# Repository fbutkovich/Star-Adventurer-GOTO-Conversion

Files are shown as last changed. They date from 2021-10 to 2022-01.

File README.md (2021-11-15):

# Star-Adventurer-GOTO-Conversion
Source code, schematics and 3D printing files for the conversion of the SkyWatcher Star Adventurer to a full GOTO equatorial telescope mount. The conversion will require soldering skills in order to splice the yellow and blue wires from the 
brushed DC motor inside the stock SA. The current version of the Python GUI was developed with Python 3.9. The included "Adafruit_Motor_Shield_V2_Library" MUST be used vs. the default version available to the public, as it was modified to 
support accurate stepper motor stepping. The helper library "ParseMotorParameters" must also be placed inside the C:\Users\username\Documents\Arduino\libraries folder if modifying/re-uploading the source code. 

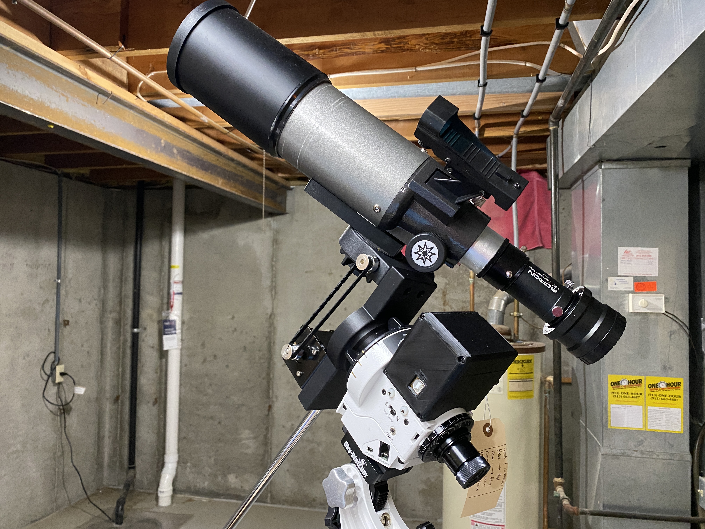
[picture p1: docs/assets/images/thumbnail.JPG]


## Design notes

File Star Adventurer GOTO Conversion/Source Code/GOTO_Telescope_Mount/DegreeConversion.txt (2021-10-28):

The following is a conversion method for how long the RA motor inside the Star Adventuerer should run in seconds to 
move the RA axis a given amount of degrees.

Motor shaft -> 1st spur gear is 327:1 possibly 350:1?

18RPM on 1st spur gear * 327 = 5886RPM

5886RPM/70000=0.084RPM

1/0.084RPM=12m

360deg/12m=30deg/m=0.5deg/s

to move 5deg it would take 5/0.5=10s/60s=0m10s

total reduction ratio between motor shaft and dovetail bracket is 70000:1

With the speed set to 150(5886RPM), the voltage is 7.5V across the motor which is optimal.

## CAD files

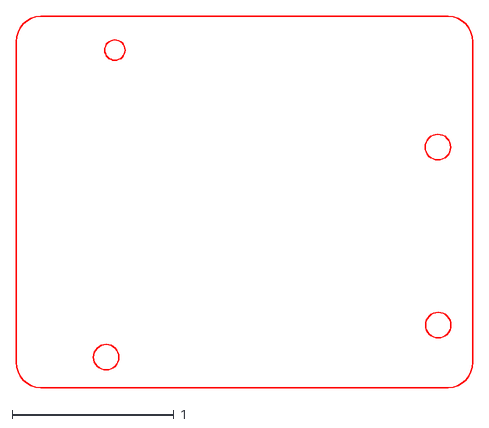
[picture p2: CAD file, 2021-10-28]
Star Adventurer GOTO Conversion/3D Files/Arduino Holes Pattern/CNC_UNO_mount1.dxf
2.82 x 2.30

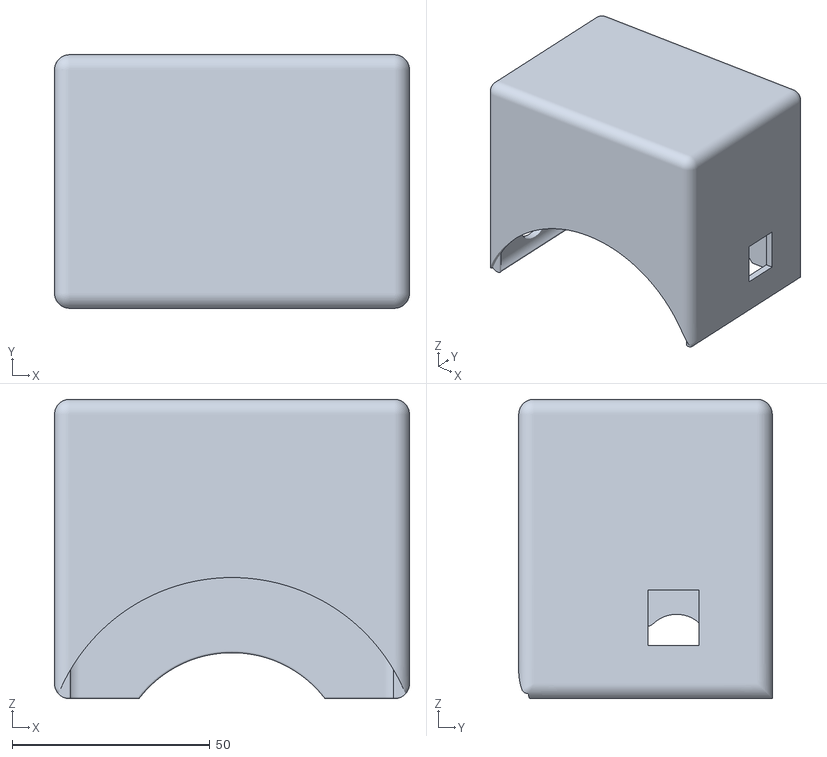
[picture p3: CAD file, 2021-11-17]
Star Adventurer GOTO Conversion/3D Files/SA Custom Electronics Enclosure Overmolding.stl
89.7 x 64.1 x 75.7

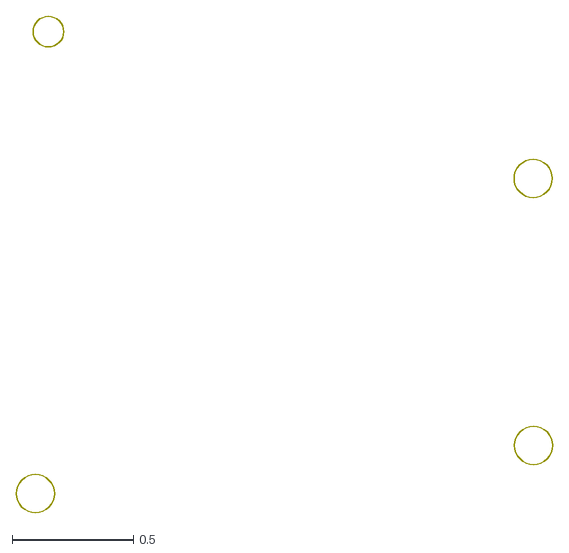
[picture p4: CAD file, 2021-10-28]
Star Adventurer GOTO Conversion/3D Files/Arduino Holes Pattern/CNC_UNO_holes.dxf
2.21 x 2.05

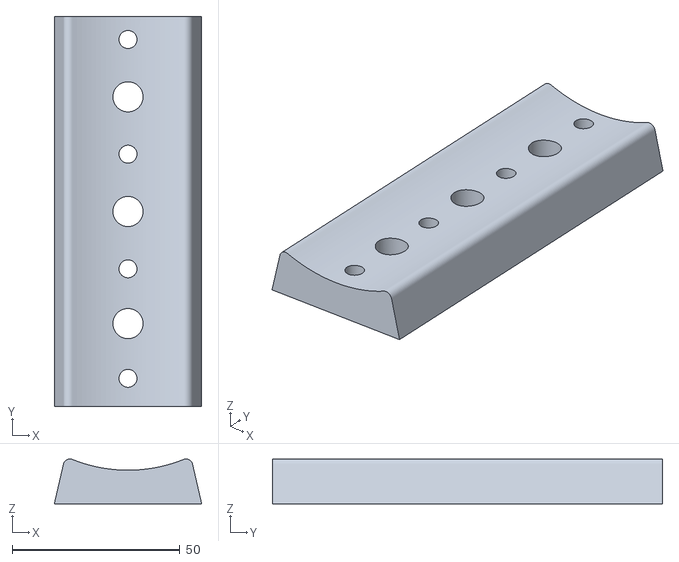
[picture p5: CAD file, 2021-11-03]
Star Adventurer GOTO Conversion/3D Files/Extended Dovetail Rail.stl
44.0 x 116.4 x 13.4

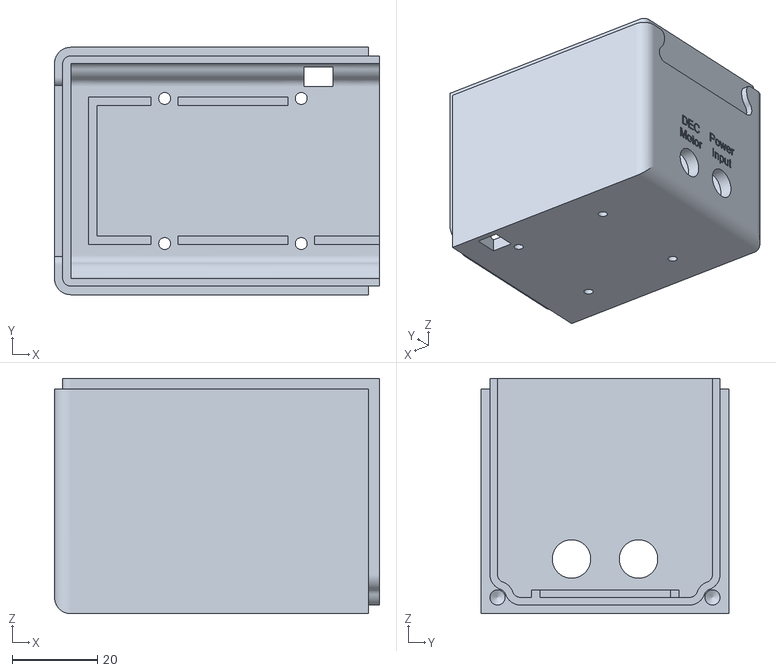
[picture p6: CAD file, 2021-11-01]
Star Adventurer GOTO Conversion/3D Files/SA Custom Electronics Enclosure Bottom.stl
76.2 x 58.0 x 55.2

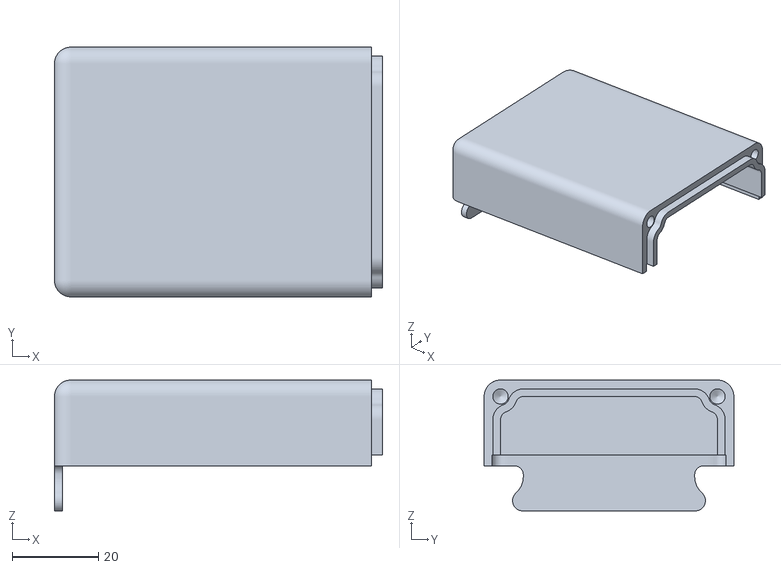
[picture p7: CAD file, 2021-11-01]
Star Adventurer GOTO Conversion/3D Files/SA Custom Electronics Enclosure Top.stl
76.2 x 58.0 x 30.4

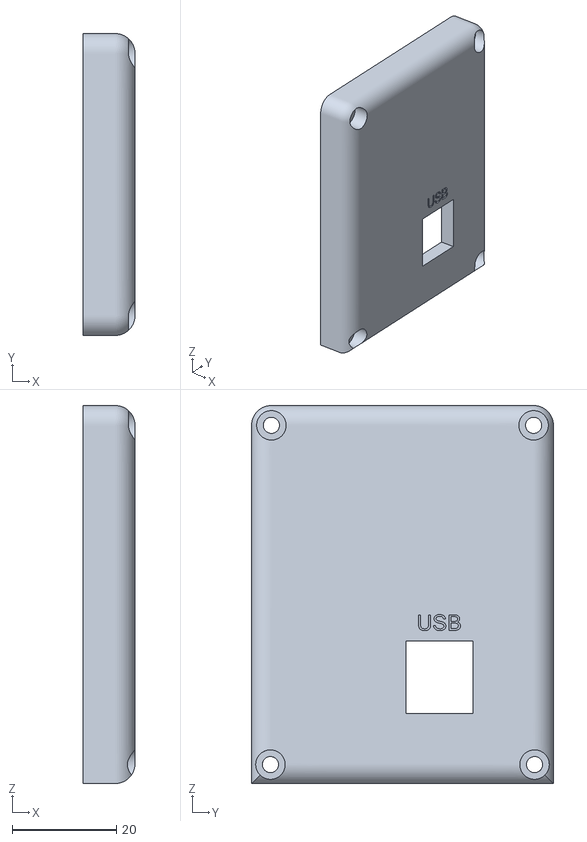
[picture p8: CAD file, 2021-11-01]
Star Adventurer GOTO Conversion/3D Files/SA Custom Electronics Enclosure Side.stl
10.0 x 58.0 x 72.6

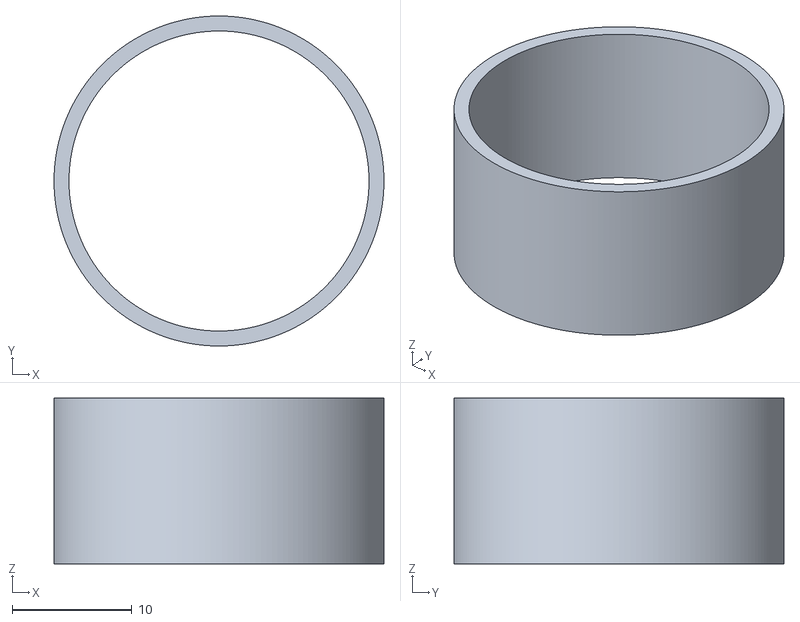
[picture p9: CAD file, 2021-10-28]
Star Adventurer GOTO Conversion/3D Files/SA Motor Declination Bracket Polar Scope Illuminator.stl
27.5 x 27.5 x 13.8

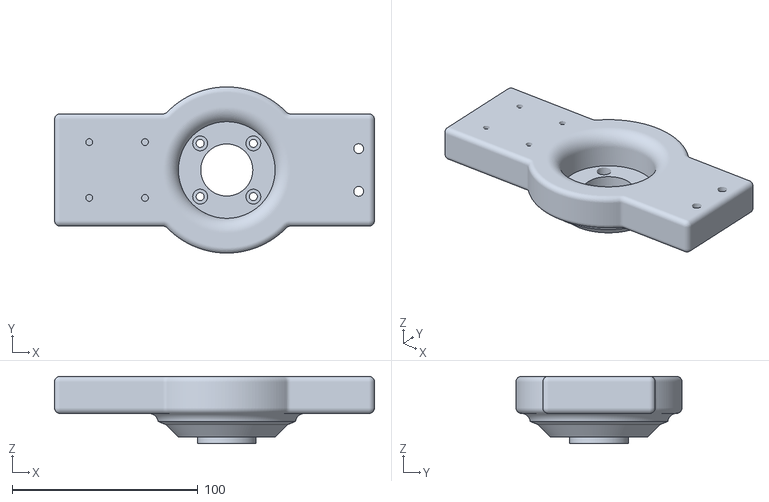
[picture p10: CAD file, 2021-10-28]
Star Adventurer GOTO Conversion/3D Files/SA Motor Declination Bracket.stl
172.2 x 89.4 x 36.3

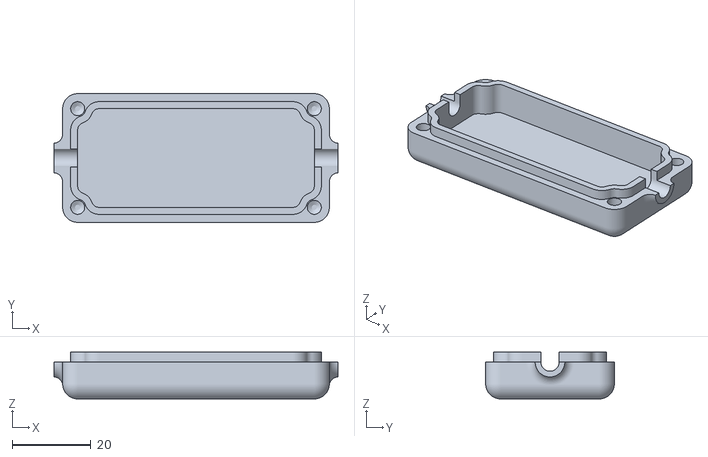
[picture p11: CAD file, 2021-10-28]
Star Adventurer GOTO Conversion/3D Files/DC Converter Enclosure Bottom.stl
71.9 x 32.6 x 11.8

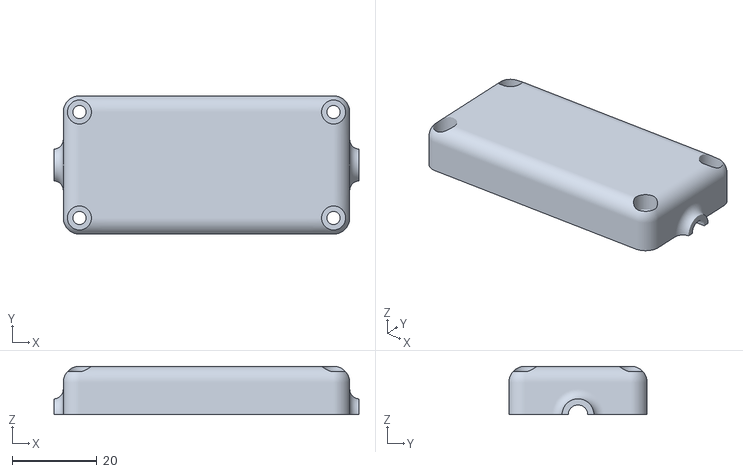
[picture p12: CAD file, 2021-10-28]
Star Adventurer GOTO Conversion/3D Files/DC Converter Enclosure Top.stl
71.9 x 32.6 x 11.4

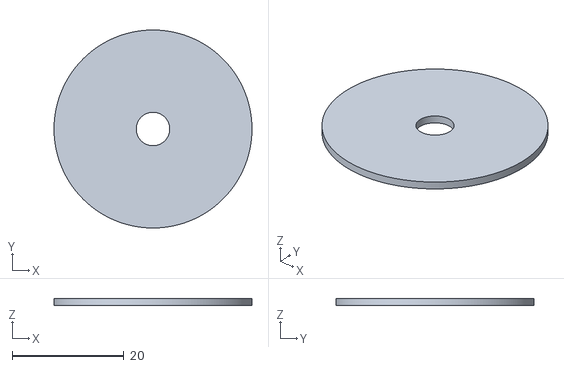
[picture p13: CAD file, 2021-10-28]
Star Adventurer GOTO Conversion/3D Files/Sky Watcher Equitorial Wedge Shim.stl
35.5 x 35.5 x 1.25

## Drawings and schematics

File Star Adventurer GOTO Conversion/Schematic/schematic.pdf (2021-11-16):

M

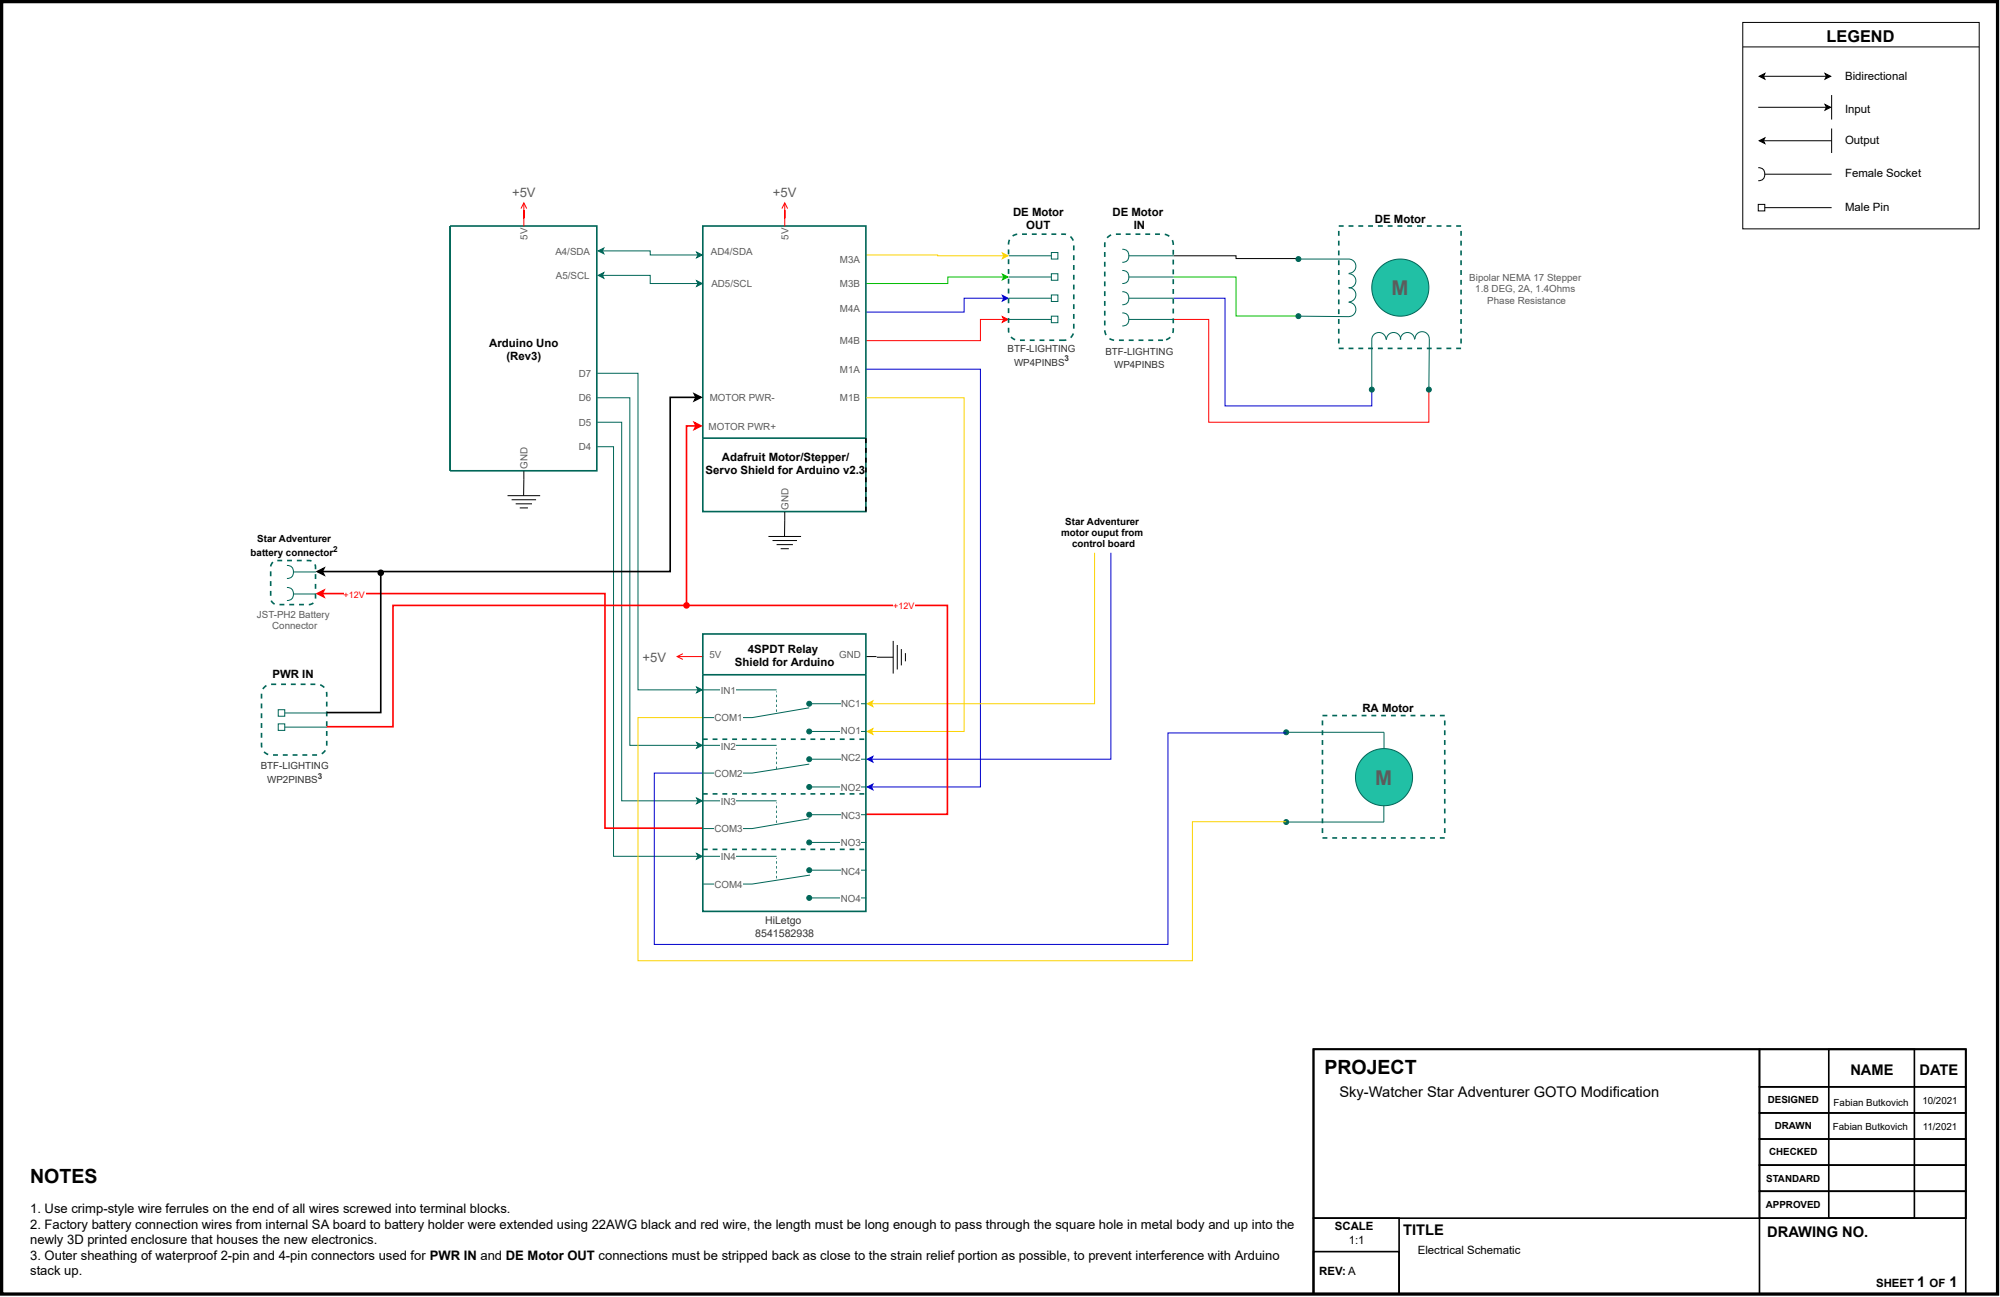
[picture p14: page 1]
Arduino Uno (Rev3); A5/SCL; A4/SDA; AD4/SDA; AD5/SCL; GND; RA Motor; MOTOR PWR-; MOTOR PWR+; BTF-LIGHTING WP2PINBS³; PWR IN; BTF-LIGHTING WP4PINBS; DE Motor IN; BTF-LIGHTING WP4PINBS³; DE Motor OUT; Star Adventurer battery connector²; JST-PH2 Battery Connector; COM1; COM2; COM3; COM4; HiLetgo 8541582938; DE Motor; DRAWING NO.; SHEET 1 OF 1; TITLE; SCALE; NAME; DATE; REV:; DESIGNED; DRAWN; CHECKED; STANDARD; APPROVED; Electrical Schematic; Fabian Butkovich; NOTES; LEGEND; Bidirectional; Input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

Bipolar NEMA 17 Stepper
1.8 DEG, 2A, 1.4Ohms
Phase Resistance

Adafruit Motor/Stepper/
Servo Shield for Arduino v2.3 GND

Star Adventurer
motor ouput from
control board

4SPDT Relay
Shield for Arduino

PROJECT
Sky-Watcher Star Adventurer GOTO Modification

1. Use crimp-style wire ferrules on the end of all wires screwed into terminal blocks.
2. Factory battery connection wires from internal SA board to battery holder were extended using 22AWG black and red wire, the length must be long enough to pass through the square hole in metal body and up into the
newly 3D printed enclosure that houses the new electronics.
3. Outer sheathing of waterproof 2-pin and 4-pin connectors used for PWR IN and DE Motor OUT connections must be stripped back as close to the strain relief portion as possible, to prevent interference with Arduino
stack up.

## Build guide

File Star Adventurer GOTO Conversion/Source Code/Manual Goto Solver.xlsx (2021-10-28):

Source Right Ascension (hh) | Destination Right Ascension (hh) | Source Right Ascension (mm) | Destination Right Ascension (mm) | Source Declination (Deg) | Destination Declination (Deg) | RA Difference (h:mm:ss) | DEC Difference (Deg)
18 | 20 | 37 | 0 | 38 | 22 | -83.00 | 16
Time to Run Star Adventurer N in 12X Mode (mm:ss)
0:07:32
Number of Declination Knob Turns (CCW)
5.3
Number of Declination Knob Increments
53.3
0:00:38
0:06:54
0:08:11

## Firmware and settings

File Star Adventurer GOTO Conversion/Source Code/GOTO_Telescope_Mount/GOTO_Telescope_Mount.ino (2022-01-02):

/*
   This code is resposible for controlling two motors on the SkyWatcher Star Adventuer tracking mount for the purpose of converting it into a full equitorial slewing mount. The final
   mount conversion has two degrees of motion control: right acension RA and declination DEC. This source code requires the ParseMotorParameters helper library which can be found at the following
   github archive https://github.com/fbutkovich/Star-Adventurer-GOTO-Conversion

   To control the motors, a serial input string is read and parsed into five separate parameters which are formatted as follows (motor ID, motor direction, motor speed, degrees to move
   , tracking enabled). Motor ID 0 represents the RA motor, and motor ID 1 represents the DEC motor, direction is 0 for clockwise and 1 for counter-clockwise, speed is in RPMs and is ignored
   for the RA axis as it moves at a fixed speed, tracking enabled is 0 for disabled and 1 for enabled. 

   This source code is meant to be used in conjunction with the python user interface SAGOTOGUI.py, which can set a current celestial
   coordinate and destination coordinate and then compute the difference between the two and perform a telescope slew in both RA and DEC axis'
   Created by Fabian Butkovich, September, 2021.
*/

#include <Adafruit_MotorShield.h>
#include <ParseMotorParameters.h>
#include <Adafruit_PWMServoDriver.h>

#define DEBUG 1

//Create the motor shield object with the default I2C address
Adafruit_MotorShield AFMS = Adafruit_MotorShield();

/*Stepper motor with 200 steps per revolution (1.8 degree) to motor port #2 (M3 and M4) on motor driver board. This motor
  is responsible for driving the declination axis*/
Adafruit_StepperMotor *DECMOTOR = AFMS.getStepper(200, 2);

/*DC motor connected to motor port #1 (M1 and M2) on motor driver board. This motor
  is responsible for driving the right ascension axis*/
Adafruit_DCMotor *RAMOTOR = AFMS.getMotor(1);

/* Create an instance of the ParseMotorParameters class, which takes the incoming input serial string and separates it
    into five different variables used to control the behavior of the stepper motor(s)
*/
ParseMotorParameters parsemotorparameters;

//Local variables for storing motor behavior parameters returned from the parsemotorparameters class
int RASpeed;

/*Definition of physcial pins used to control two relays on the relay shield which are responsible for switching the power
  to the RA motor between the motor shield or the default Star Adventuerer driver board*/
#define RA1Relay 6
#define RA2Relay 7
/*Definition of physcial pins used to control relay on the relay shield which is responsible for toggling the direction
  the Star Adventuerer is tracking (N/S)*/
#define N_SRelay 5
#define TrackingENABLE 4

/*This constant is derived from the method described in DegreeConversion.txt and is used to convert degrees of motion
  to runtime in seconds of the RA motor*/
const float DEG_PER_SEC = 0.5;

//long positive integer for storing interval to wait before turning RA motor OFF
unsigned long runinterval;

unsigned long previousMillis = 0;

//Boolean variables for storing state changes
bool CheckRAStatus = false;

void setup()
{
  Serial.begin(9600);
  //Begin serial I2C communication with adafruit motor shield @ 500Hz
  AFMS.begin(500);
  /*Setting the speed of the RA motor speed constant, this speed parameter does not directly correlate to RPM, instead
    reference DegreeConversion.txt for the steps taken to derive RPM equivalent*/
  RASpeed = 150;
  //Initialize pins for controlling two relays that switch the motor power for the Right Ascension axis to two different paths
  pinMode(RA1Relay, OUTPUT);
  pinMode(RA2Relay, OUTPUT);
  //This relay is unused but can be used if tracking direction control is desired (e.g. N/S)
  pinMode(N_SRelay, OUTPUT);
  //This relay controls the 12V power provided to the SA internal control board to either enable/disabled star tracking
  pinMode(TrackingENABLE, OUTPUT);
  digitalWrite(RA1Relay, LOW);
  digitalWrite(RA2Relay, LOW);
  //Default SA N tracking mode for northern hemisphere
  digitalWrite(N_SRelay, LOW);
  //Default enabled power to the SA
  digitalWrite(TrackingENABLE, LOW);
}

void loop()
{
  /*Use the millis() function which returns the number of milliseconds elapsed since the start of the code loop, this is used
    to calculate how long the Right Ascension motor has been on and when it should be shut off*/
  unsigned long currentMillis = millis();
  if (Serial.available() > 0)
  {
    //Read char array input from serial monitor and store it within a string datatype
    String input = Serial.readStringUntil('\n');
    /*Pass the string to the class member "ParseInput" of the parsemotorparameters class instance, which will
      retrieve the motor behavior parameters such as speed and steps to move and return a true boolean which sets the motor run state variable*/
    parsemotorparameters.ParseInput(input);
    /*If motor ID returned from "ParseInput" is 1, then run the RA motor for calculated period of time that translates to
      degrees moved*/
    if (parsemotorparameters.ReturnMotorId() == 0)
    {
      runRAmotor(currentMillis);
    }
    else
    {
      runDECmotor();
    }
#if DEBUG == 1
    debug();
#endif
  }
  //Check to see if the RA motor should be turned off by comparing the delta between currentMillis and previousMillis
  if (CheckRAStatus && currentMillis - previousMillis > runinterval)
  {
    RAMOTOR->fullOff();
    //Switch the RA motor physical connections back to the power provided by the Star Adventurer control board for accurate tracking
    digitalWrite(RA1Relay, LOW);
    digitalWrite(RA2Relay, LOW);
    /*Toggle power to the Star Adventurer control board to reset tracking after a move is performed, if tracking is
      disabled when the input serial string is given (0=disabled, 1=enabled), then the SA power will not be restored*/
    if (parsemotorparameters.ReturnTrackingEnabled() == 1)
    {
      digitalWrite(TrackingENABLE, LOW);
    }
#if DEBUG == 1
    Serial.println("OFF");
    Serial.println("------------------------------");
#endif
    CheckRAStatus = false;
  }
}

void runRAmotor(unsigned long currentMillis)
{
  //Switch the RA motor physical connections to the power provided by the Adafruit motor shield for fast slewing
  digitalWrite(RA1Relay, HIGH);
  digitalWrite(RA2Relay, HIGH);
  //Toggle power to the Star Adventurer control board to reset tracking after a move is performed
  digitalWrite(TrackingENABLE, HIGH);
  //Set the runtime in seconds for the RA motor
  runinterval = parsemotorparameters.ReturnMotorRuntime(DEG_PER_SEC);
  //Restart the non-blocking millis() timer which is used to check how long the RA motor has been running
  previousMillis = currentMillis;
  //Setting the speed of the RA motor
  RAMOTOR->setSpeed(RASpeed);
  RAMOTOR->run(parsemotorparameters.ReturnMotorDirection());
  CheckRAStatus = true;
}

void runDECmotor()
{
  DECMOTOR->setSpeed(parsemotorparameters.ReturnMotorSpeed());
  DECMOTOR->step(parsemotorparameters.ReturnMotorSteps(), parsemotorparameters.ReturnMotorDirection(), DOUBLE);
  DECMOTOR->release();
}

#if DEBUG == 1
//This function prints debugging information
void debug()
{
  //Retrieve debugging info
  if (parsemotorparameters.ReturnMotorId() == 1)
  {
    Serial.println("Motor: DEC");
    Serial.print("Speed: ");
    Serial.print(parsemotorparameters.ReturnMotorSpeed());
    Serial.println("RPM");
    if (parsemotorparameters.ReturnMotorDirection() == 1)
    {
      Serial.println("Direction: CW");
    }
    else if (parsemotorparameters.ReturnMotorDirection() == 2)
    {
      Serial.println("Direction: CCW");
    }
    Serial.print("Motor Steps: ");
    Serial.println(parsemotorparameters.ReturnMotorSteps());
    Serial.print("Normal Tracking Enabled?: ");
    Serial.println(parsemotorparameters.ReturnTrackingEnabled());
  }
  else if (parsemotorparameters.ReturnMotorId() == 0)
  {
    Serial.println("Motor: RA");
    Serial.print("Speed: ");
    Serial.print(5886);
    Serial.println("RPM");
    if (parsemotorparameters.ReturnMotorDirection() == 1)
    {
      Serial.println("Direction: CW");
    }
    else if (parsemotorparameters.ReturnMotorDirection() == 2)
    {
      Serial.println("Direction: CCW");
    }
    Serial.print("Motor Runtime: ");
    Serial.print(runinterval);
    Serial.println("ms");
    Serial.print("Normal Tracking Enabled?: ");
    Serial.println(parsemotorparameters.ReturnTrackingEnabled());
  }
  Serial.println("------------------------------");
}
#endif

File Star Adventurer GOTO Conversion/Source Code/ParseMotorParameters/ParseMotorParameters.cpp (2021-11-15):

/*
  ParseMotorParameters.h - Library for parsing serial data input parameters for controlling a standard 1.8deg NEMA 17 stepper motor and standard 
  DC brushed motor, the input parameters are received in the following format: (motorId, motorDirection, motorSpeed(RPM), motorDegrees, trackingEnabled). 
  An example is "1,1,20,320,1", which would translate to moving the stepper motor at 20RPMs counterclockwise for 177 1.8 degree steps with normal tracking 
  set to resume after the move is performed. 
  Created by Fabian Butkovich, September, 2021.
*/
#include "Arduino.h"
#include "ParseMotorParameters.h"

int index = 0;
//Array to store positions of delimiter characters
int delimiterPos[4];

String numbers[5] = {"", "", "", "", ""};

ParseMotorParameters::ParseMotorParameters()
{
}

void ParseMotorParameters::ParseInput(String input)
{
  //Reset the input string,
  for (int x = 0; x < 5; x++) 
  {
    numbers[x] = "";
  }
  index = 0;
  //Step through string and retrieve positon of each delimiter, assign the position number to the current delimiter# 1-3
  for (int i = 0; i < input.length(); i++) 
  {
    if (input[i] == ',') 
	{
      delimiterPos[index] = i;
      index++;
    }
  }
  //Append number string 1 with all the characters in the input string before the first delimiter
  for (int i = 0; i < delimiterPos[0]; i++) 
  {
    if (input[i] != ',') 
	{
      numbers[0] += input[i];
    }
  }
  //Append number string 2 with all the characters in the input string after the first delimiter
  for (int i = delimiterPos[0]; i < delimiterPos[1]; i++) 
  {
    if (input[i] != ',') 
	{
      numbers[1] += input[i];
    }
  }
  //Append number string 3 with all the characters in the input string after the second delimiter
  for (int i = delimiterPos[1]; i < delimiterPos[2]; i++) 
  {
    if (input[i] != ',') 
	{
      numbers[2] += input[i];
    }
  }
  //Append number string 4 with all the characters in the input string after the third delimiter
  for (int i = delimiterPos[2]; i < delimiterPos[3]; i++) 
  {
    if (input[i] != ',') 
	{
      numbers[3] += input[i];
    }
  }
  //Append number string 5 with all the characters in the input string after the fourth delimiter
  for (int i = delimiterPos[3]; i < input.length(); i++) 
  {
    if (input[i] != ',') 
	{
      numbers[4] += input[i];
    }
  }
}

int ParseMotorParameters::ReturnMotorId()
{
  //Only accept a 0 or 1 for motor Id input, motor ID 0 represents the stepper motor for control of the DEC axis, and ID 1 is for the RA motor
  if (numbers[0] == "0" || numbers[0] == "1")
  {
    return numbers[0].toInt();
  }
  else
  {
    return 0;
  }
}

int ParseMotorParameters::ReturnMotorSpeed()
{
  return numbers[2].toInt();
}

//Input degrees to move must be multiplied by 122 since the gear reduction of the declination worm wheel is 122:1, the C++ function "toFloat()" is used since we need 1/10th of a degree precision
int ParseMotorParameters::ReturnMotorSteps()
{
  return (numbers[3].toFloat() * 122) / 1.8;
}

//This function accepts a known constant "DEG_PER_SEC" and uses it to convert degrees of motion to runtime in seconds of the RA motor, the C++ function "toFloat()" is used since we need 1/10th of a degree precision
//A compensation factor is applied to the input degrees to move as (0.042*runtime) degrees of normal tracking will be lost during the entire time the RA axis is performing a move
unsigned long ParseMotorParameters::ReturnMotorRuntime(float DEG_PER_SEC)
{
  return ((numbers[3].toFloat() + (0.042 * (numbers[3].toFloat() / DEG_PER_SEC))) / DEG_PER_SEC) * 1000;
}

int ParseMotorParameters::ReturnMotorDirection()
{
  if (numbers[1] == "1")
  {
	//Clockwise rotation
    return 1;
  }
  else if (numbers[1] == "0")
  {
    //Counter-clockwise rotation
    return 2;
  }
  else
  {
    return 0;
  }
}

bool ParseMotorParameters::ReturnTrackingEnabled()
{
  if (numbers[4].toInt() == 1)
  {
    return true;
  }
  else
  {
    return false;
  }
}

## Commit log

2021-10-28 Initial add and commit of all files
    [DC Converter Enclosure Bottom.stl, DC Converter Enclosure Top.stl, Manual Goto Solver.xlsx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]
2021-10-28 Added dxfs for holes patterns of arduino
    [CNC_UNO_holes.dxf, CNC_UNO_mount1.dxf]
2021-10-28 ParseMotorParameters Library Change
    Removed local library folder for ParseMotorParameters and instead turned it into a global library for Arduino. Added keywords.txt to ParseMotorParameters library for color mapping of functions and cl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
2021-10-29 Redesign of electronics enclosure bottom half
    [SA Custom Electronics Enclosure Bottom.stl]
2021-10-29 Changed bed adhesion on electronics enclosure to raft
2021-11-01 Regenerated gcode files with new slicer settings
    [SA Custom Electronics Enclosure Side.stl, SA Custom Electronics Enclosure Top.stl]
2021-11-01 Modified bottom half of electronics enclosure and regenerated gcode
    [SA Custom Electronics Enclosure Bottom.stl]
2021-11-03 Added extended dovetail rail
    [Extended Dovetail Rail.stl]
2021-11-03 Generated gcode file for extended dovetail bracket
2021-11-04 Made numerous updates to SAGOTOGUI.py
    [SAGOTOGUI.py]
2021-11-05 Changes to source code
    Modified direction boolean behaviour so that both the RA and DE axis move in the correct direction
    [ParseMotorParameters.cpp, SAGOTOGUI.py]
2021-11-05 Changes to source code
    Updated ReturnMotorRuntime() function in ParseMotorParameters.cpp, modified python GUI SAGOTOGUI.py
    [GOTO_Telescope_Mount.ino, ParseMotorParameters.cpp, SAGOTOGUI.py]
2021-11-06 Updated GUI and Arduino source code
2021-11-07 Modified arduino source code
2021-11-08 Created and initial commit of system schematic
2021-11-09 Updates to schematic and also created a PDF version
2021-11-13 Changed hardware to physically reset power to tracker every time a GOTO move is performed
    [GOTO_Telescope_Mount.ino, SAGOTOGUI.py]
2021-11-14 Numerous updates to source code and user interace GUI
    Reversed motor ID control (0 is now RA motor and 1 is DE motor), removed ability to apply continued holding torque power on DE motor and instead replaced it with ability to toggle power to SA.
    [GOTO_Telescope_Mount.ino, ParseMotorParameters.cpp, SAGOTOGUI.py]
2021-11-15 Updated comments in both source code Arduino .ino and .cpp helper library
2021-11-16 Updated schematic, renamed "schematic.drawio.pdf" to "schematic.pdf"
2021-11-17 Design and initial add and commit of over-molding protective shell for electronics enclosure
    [SA Custom Electronics Enclosure Overmolding.stl]
2021-11-17 Added .gcode file for electronics enclosure protective over-molding
2021-12-02 Added PETG optimized .stl file for star adventurer bracket
2021-12-03 Re sliced PETG version of stl for custom declination bracket
2021-12-28 Updated source code and graphical user interface code
    Changed default serial baud rate to 9600 since it was discovered that the previous baud rate of 115200 was causing the relay which controls the power to the star adventuerer for normal tracking to op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
2021-12-28 Regenerated gcode file for DC converter enclosure
2021-12-28 Changed motor stepping style to INTERLEAVE
2021-12-29 Changed I2C communication frequency to 800Hz, changed motor step style back to DOUBLE to get more torque
2022-01-02 Changed I2C communication speed back to 500Hz
